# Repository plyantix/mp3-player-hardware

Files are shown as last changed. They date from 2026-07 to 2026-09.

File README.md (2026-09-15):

# MiniMusicBox

An open source, RP2350 based MP3 player, with LiPo battery charging, USB-C, MicroSD storage, high fidelity analog audio, and a black & white LCD screen.

Although this version of the project will work, I would not recommend building it, as it has a design flaw leading to high idle battery consumption. This will be fixed in a future revision.

This board was designed with the manufacturing tolerances of [JLCPCB](https://jlcpcb.com/) in mind.

(Incomplete) firmware [here](https://github.com/plyantix/mp3-project-software).

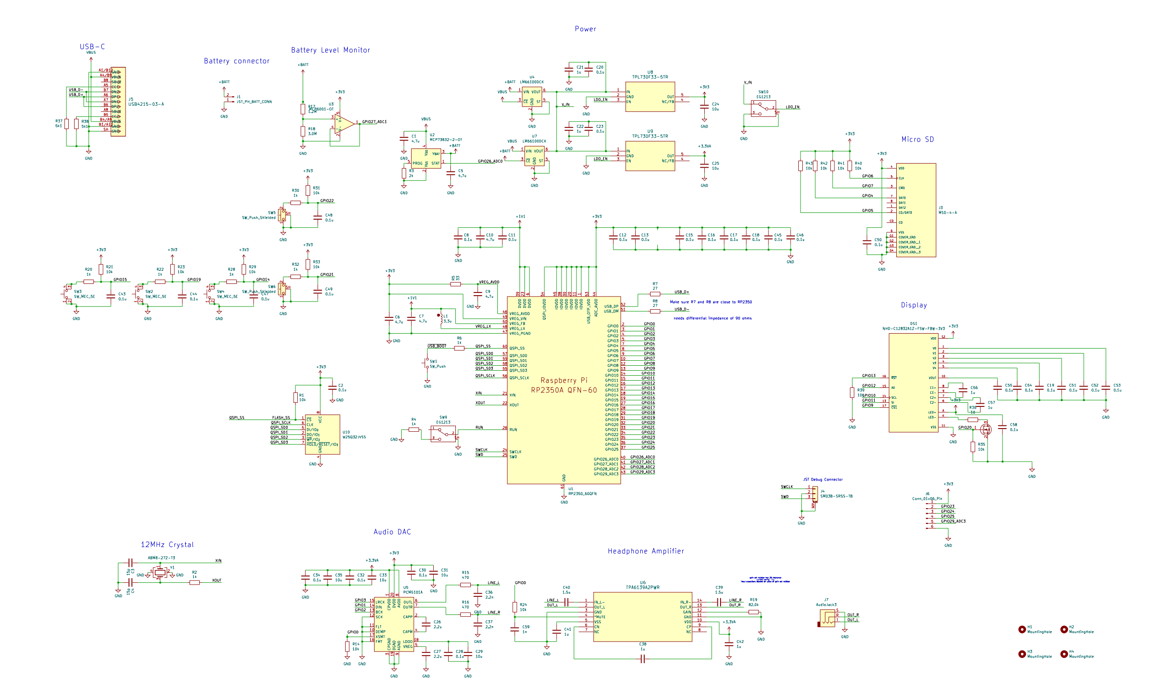
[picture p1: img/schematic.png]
PCB Schematic

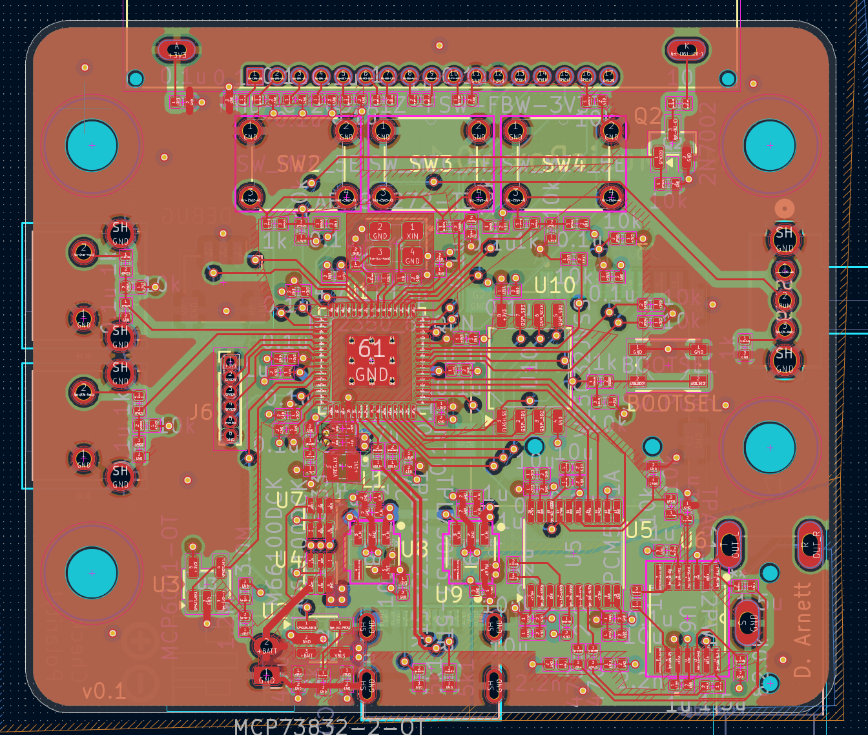
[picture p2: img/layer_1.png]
PCB layout layer 1

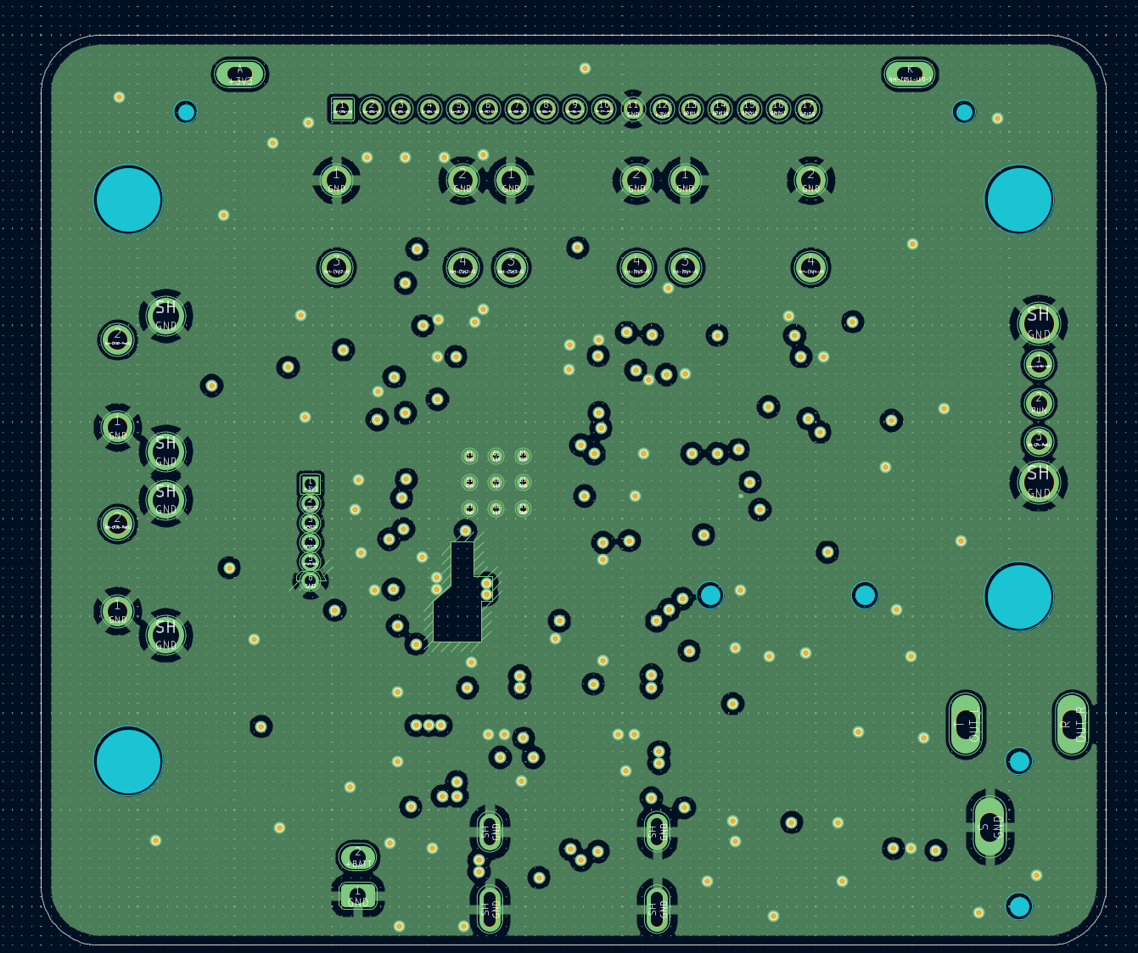
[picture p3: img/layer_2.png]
PCB layout layer 2

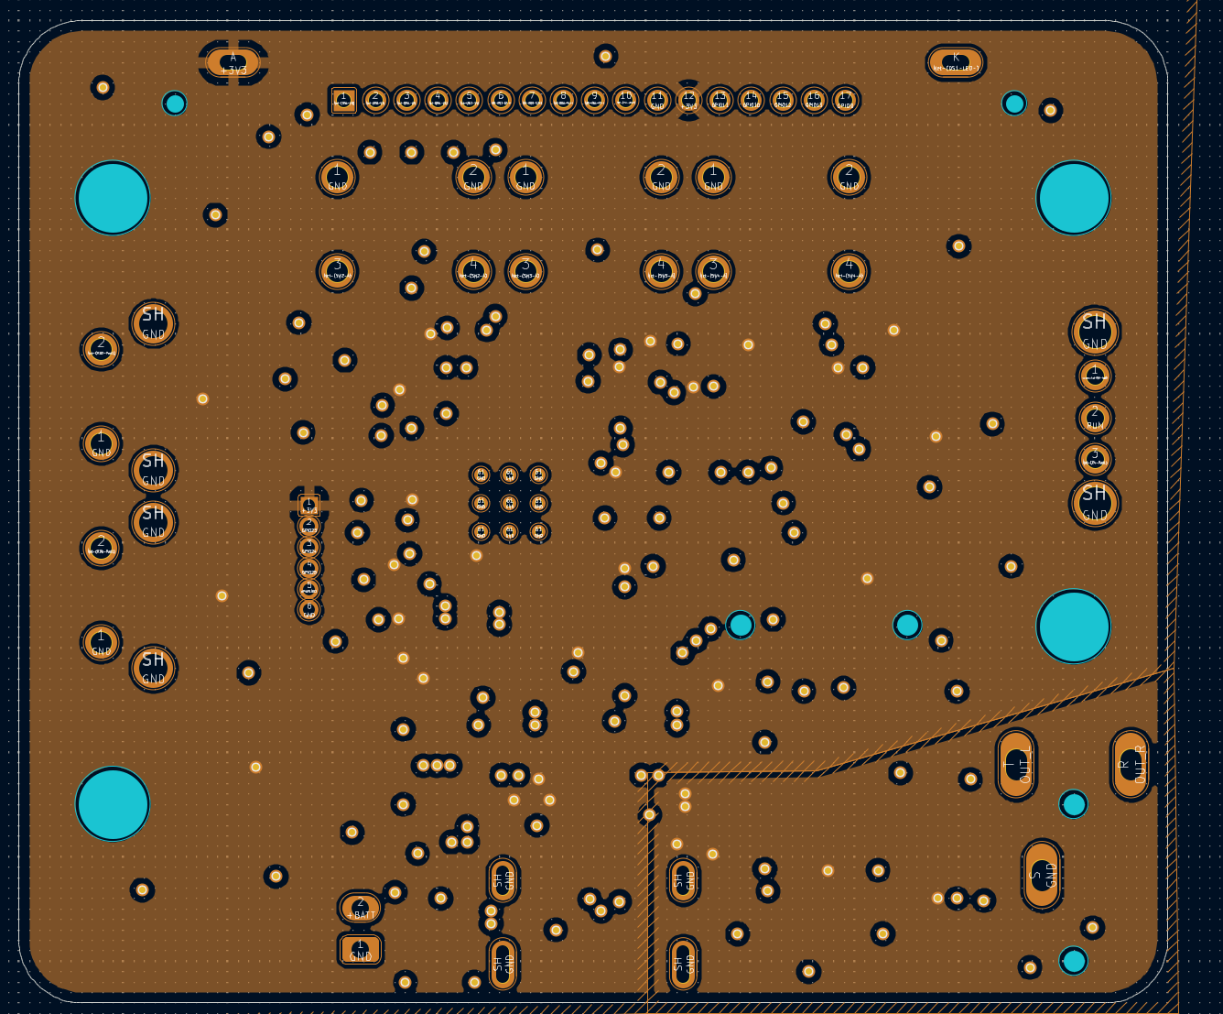
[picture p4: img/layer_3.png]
PCB layout layer 3

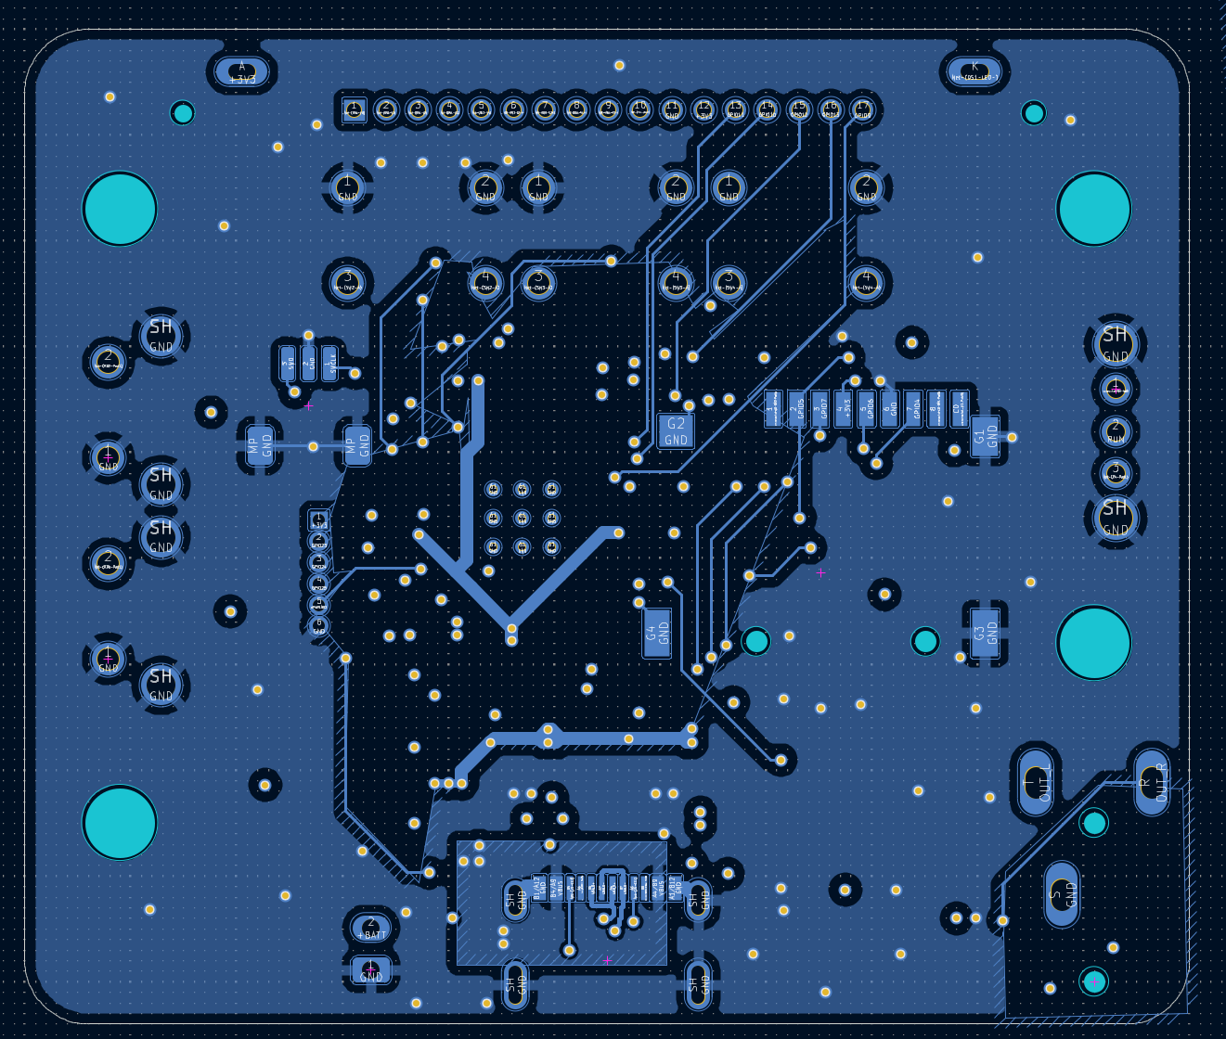
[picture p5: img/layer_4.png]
PCB layout layer 4

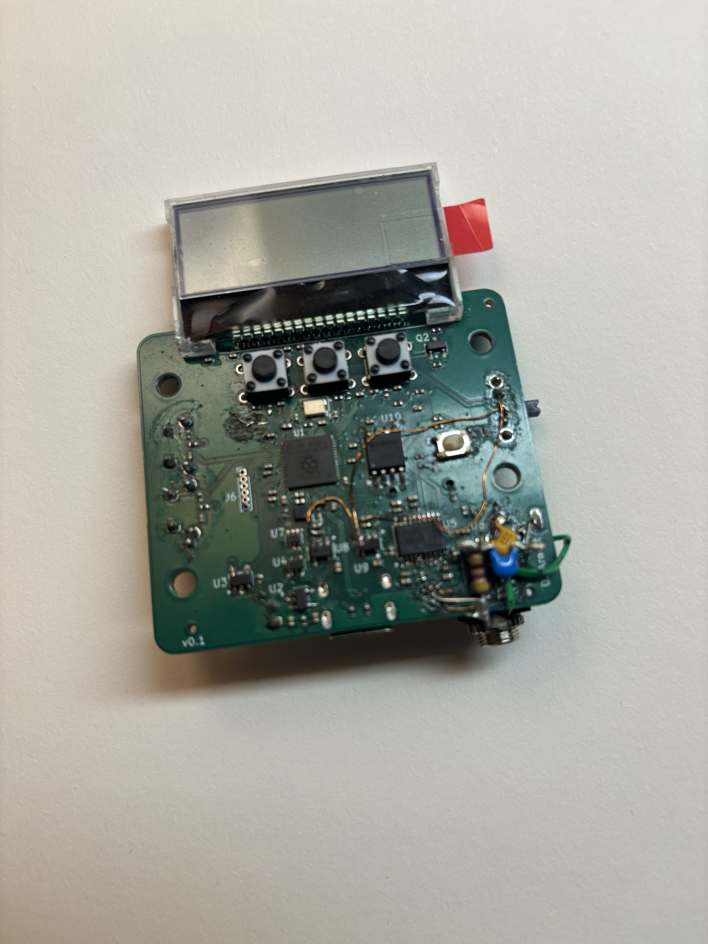
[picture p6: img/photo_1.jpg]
Photograph of fabricated and assembled PCB

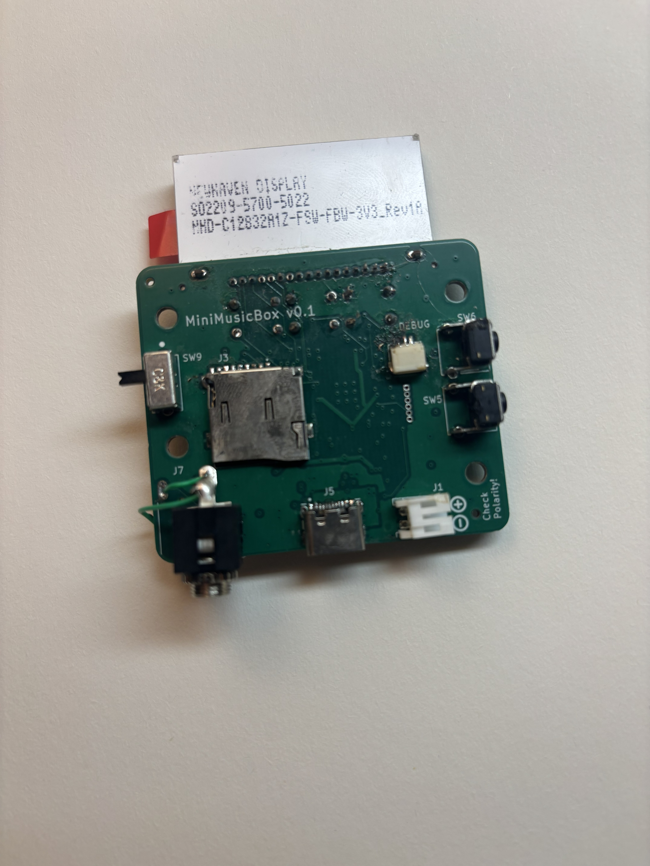
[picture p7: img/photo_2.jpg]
Backside of PCB


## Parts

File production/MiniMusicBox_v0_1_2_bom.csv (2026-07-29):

Designator | Footprint | Quantity | Value | LCSC Part #
BOOTSEL | SW_Push_1P1T_NO_Vertical_Wuerth_434133025816 | 1 | SW_Push
C1, C10, C5, C6, C7, C9 | 0402 | 6 | 4.7u
C11, C12, C13, C15, C16, C17, C18, C19, C2, C20, C23, C28, C30, C32, C34, C43, C44, C45, C46, C47, C48, C49, C50, C51, C52, C53, C54, C55, C58, C8 | 0402 | 30 | 0.1u
C21, C22, C38, C41, C42, C56, C57 | 0402 | 7 | 1u
C24, C25, C29, C31, C33, C35 | 0402 | 6 | 10u
C26, C27 | 0402 | 2 | 2.2u
C3, C4 | 0402 | 2 | 15p
C36, C37 | 0402 | 2 | 2.2n
C39, C40 | 0402 | 2 | 1.5u
C59 | 0402 | 1 | 1n
DEBUG | JST_SH_SM03B-SRSS-TB_1x03-1MP_P1.00mm_Horizontal | 1 | SM03B-SRSS-TB
DS1 | LCD_NHD-C12832A1Z-FSW-FBW-3V3 | 1 | NHD-C12832A1Z-FSW-FBW-3V3
J1 | JST_PH_S2B-PH-K_1x02_P2.00mm_Horizontal | 1 | JST_PH_BATT_CONN
J3 | CUI_MSD-4-A | 1 | MSD-4-A
J5 | CONN_8p94X6p5X3p16_12L_GCC | 1 | USB4215-03-A
J6 | PinHeader_1x06_P1.00mm_Vertical | 1 | Conn_01x06_Pin
J7 | KYCON_STX-3000 | 1 | AudioJack3
L1 | L_pol_2016 | 1 | 3.3u
Q2 | SOT-23 | 1 | 2N7002
R1, R14, R21, R23, R24, R29, R31, R33, R35, R39, R40, R41, R42, R43 | 0402 | 14 | 10k
R15, R16 | 0402 | 2 | 470
R17 | 0402 | 1 | 1.2M
R18 | 0402 | 1 | 3.0M
R19 | 0402 | 1 | 82.0k
R2, R20, R22, R28, R30, R32, R4, R6 | 0402 | 8 | 1k
R3 | 0402 | 1 | 2k
R36 | 0402 | 1 | 10
R37, R38 | 0402 | 2 | 5k1
R5 | 0402 | 1 | 33
R7, R8 | 0402 | 2 | 27
SW2, SW3, SW4 | SW4_1825910-B_TEC | 3 | SW_MEC_5E
SW5, SW6 | SW2_1825027-A_TEC | 2 | SW_Push_Shielded
SW9 | OS102011MA1QN1_CNK | 1 | EG1213
U1 | RP2350-QFN-60-1EP_7x7_P0.4mm_EP3.4x3.4mm_ThermalVias | 1 | RP2350_60QFN
U10 | SOIC-8_5.3x5.3mm_P1.27mm | 1 | W25Q32JVSS
U2 | SOT-23-5 | 1 | MCP73832-2-OT
U3 | SOT-23-5 | 1 | MCP6001-OT
U4, U7 | SOT-363_SC-70-6 | 2 | LM66100DCK
U5 | TSSOP-20_4.4x6.5mm_P0.65mm | 1 | PCM5101A
U6 | PW14 | 1 | TPA6139A2PWR
U8, U9 | SOT23-5-A_TPK | 2 | TPL730F33-5TR
Y1 | Crystal_SMD_3225-4Pin_3.2x2.5mm | 1 | ABM8-272-T3

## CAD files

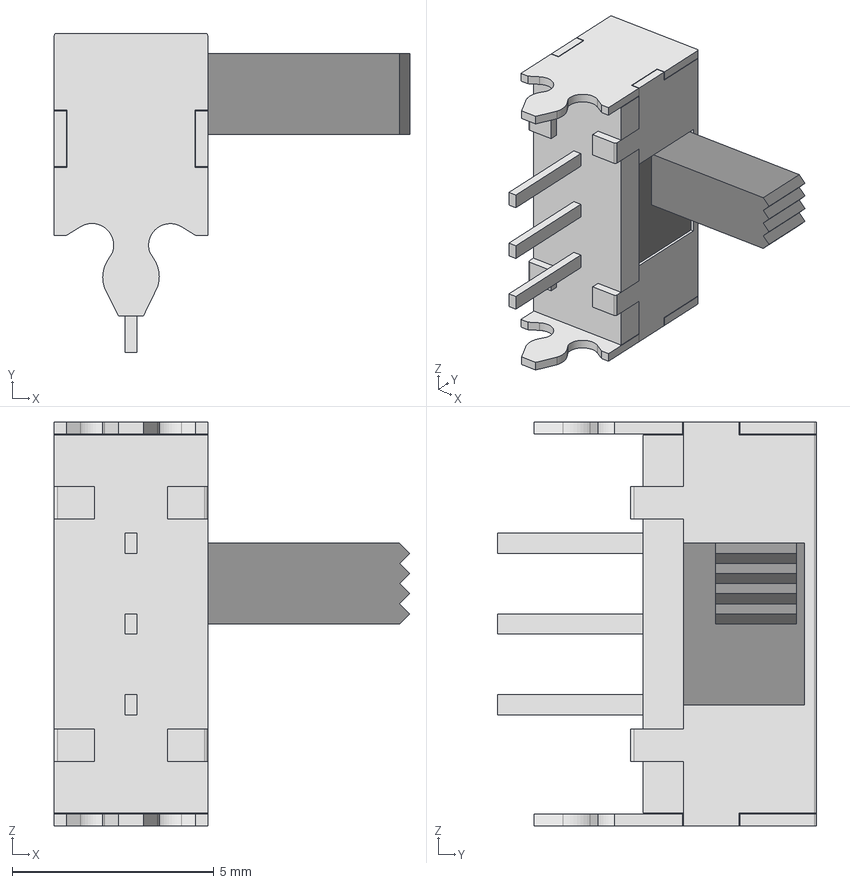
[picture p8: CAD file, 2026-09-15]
3dmodels/EG1213.step
8.80 x 7.90 x 10.00 mm

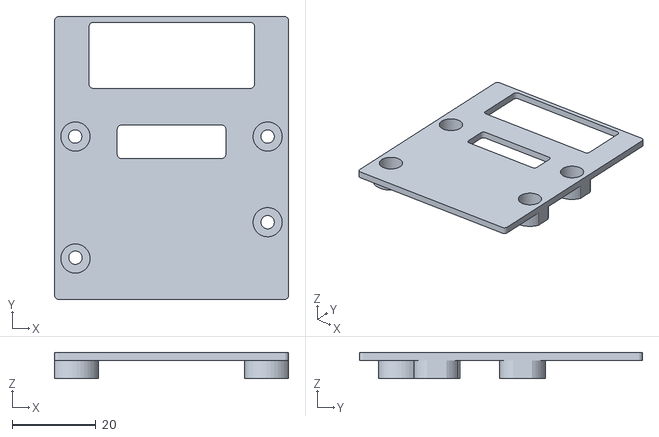
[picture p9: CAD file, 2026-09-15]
case_part2.STL
56.0 x 67.7 x 6.30

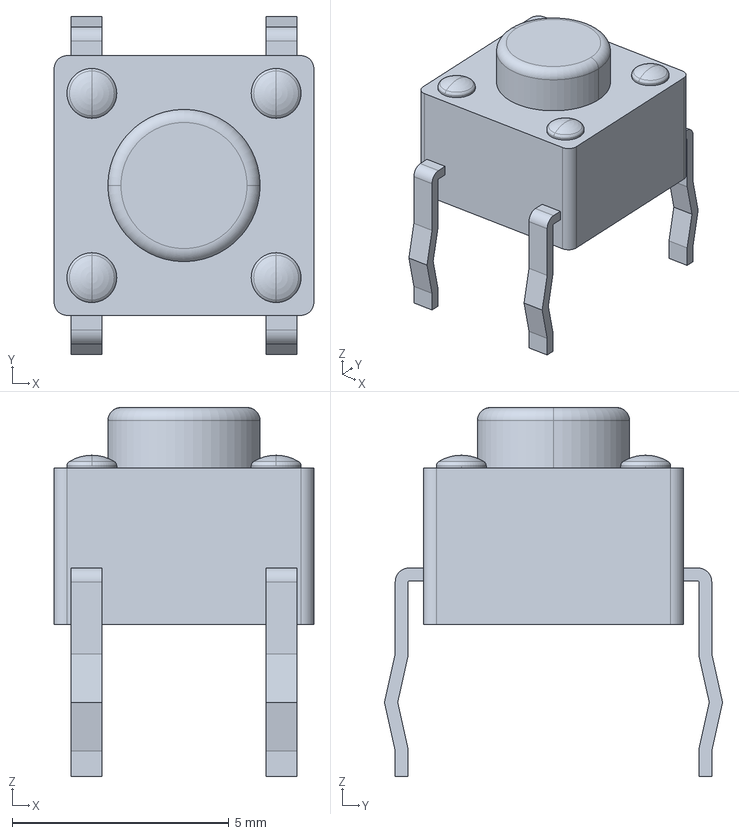
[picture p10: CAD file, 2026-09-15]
3dmodels/c-1825910-6-c-3d.stp
5.99 x 7.80 x 8.51 mm

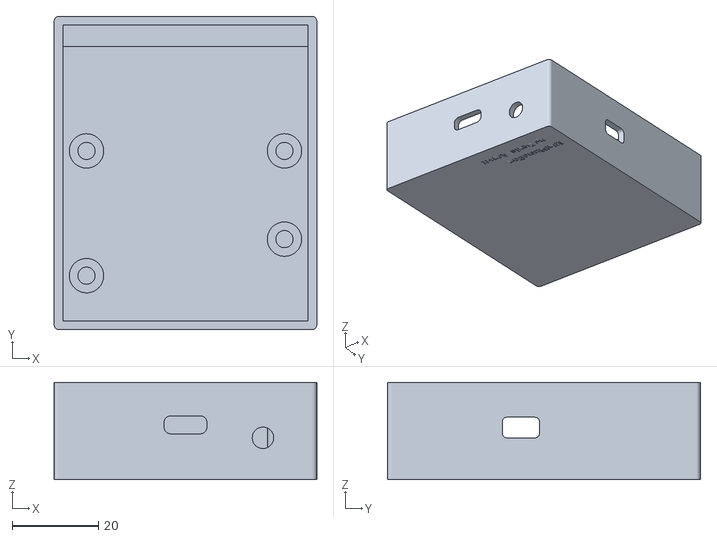
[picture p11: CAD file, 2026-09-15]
case_part1.STL
61.0 x 72.7 x 22.6

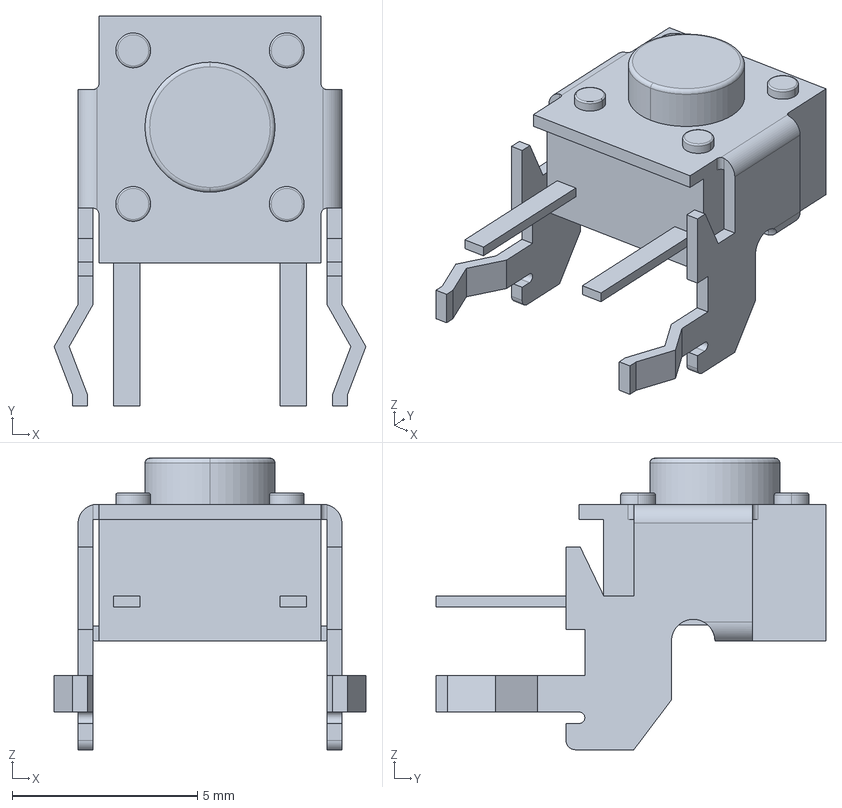
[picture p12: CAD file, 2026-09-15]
3dmodels/c-1825027-5-g-3d.stp
8.41 x 10.5 x 7.86 mm

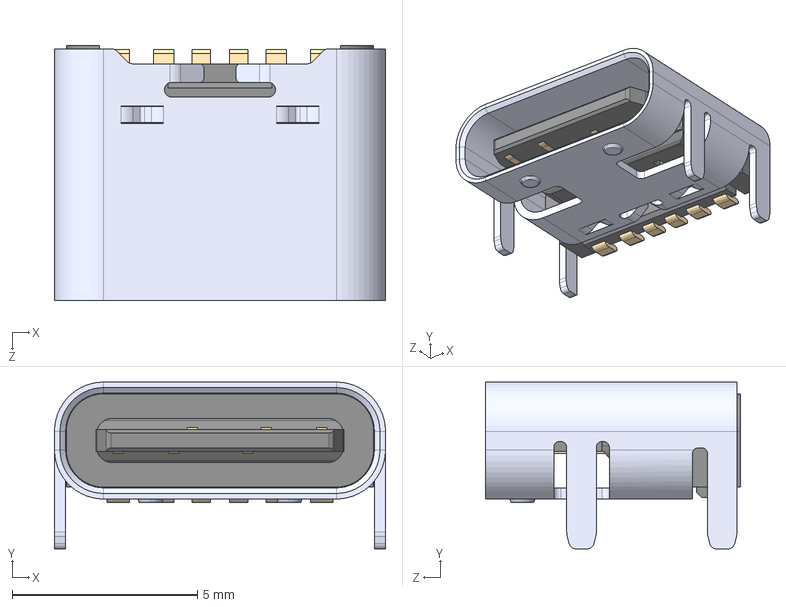
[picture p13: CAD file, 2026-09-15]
3dmodels/USB4125-GF-A_REVA2.step
8.94 x 4.51 x 6.90 mm

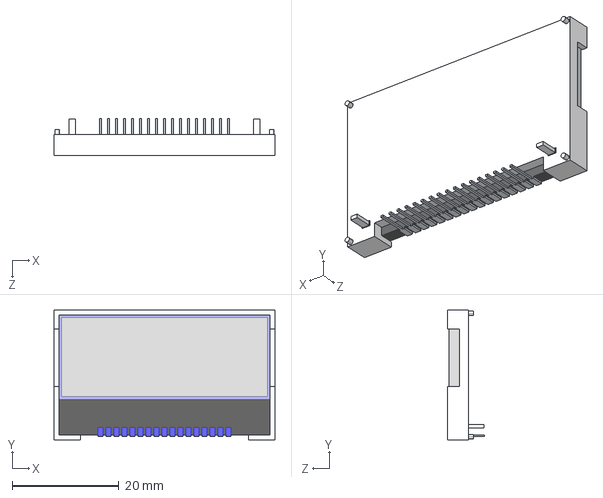
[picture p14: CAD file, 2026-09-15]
3dmodels/NHD-C12832A1Z.STEP
41.4 x 24.3 x 7.00 mm

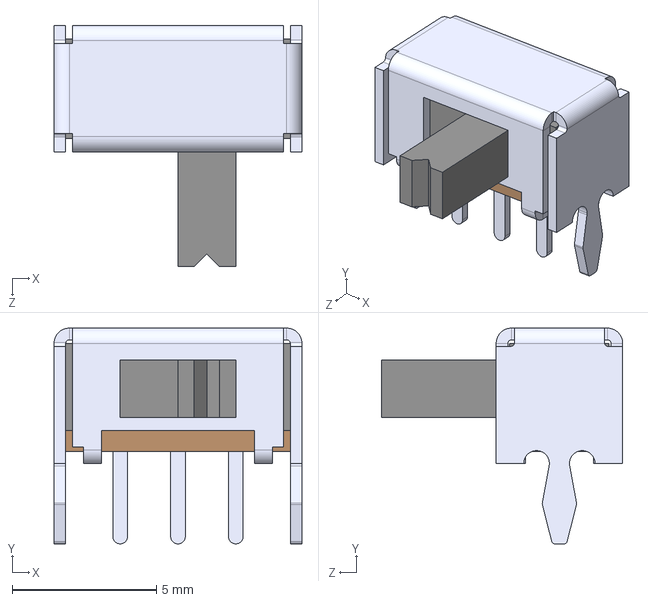
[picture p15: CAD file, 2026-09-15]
3dmodels/OS102011MA1QN1.STEP
8.61 x 7.49 x 8.38 mm

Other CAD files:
3dmodels/c-1825027-5-g-3d.stl
3dmodels/c-1825910-6-c-3d.stl

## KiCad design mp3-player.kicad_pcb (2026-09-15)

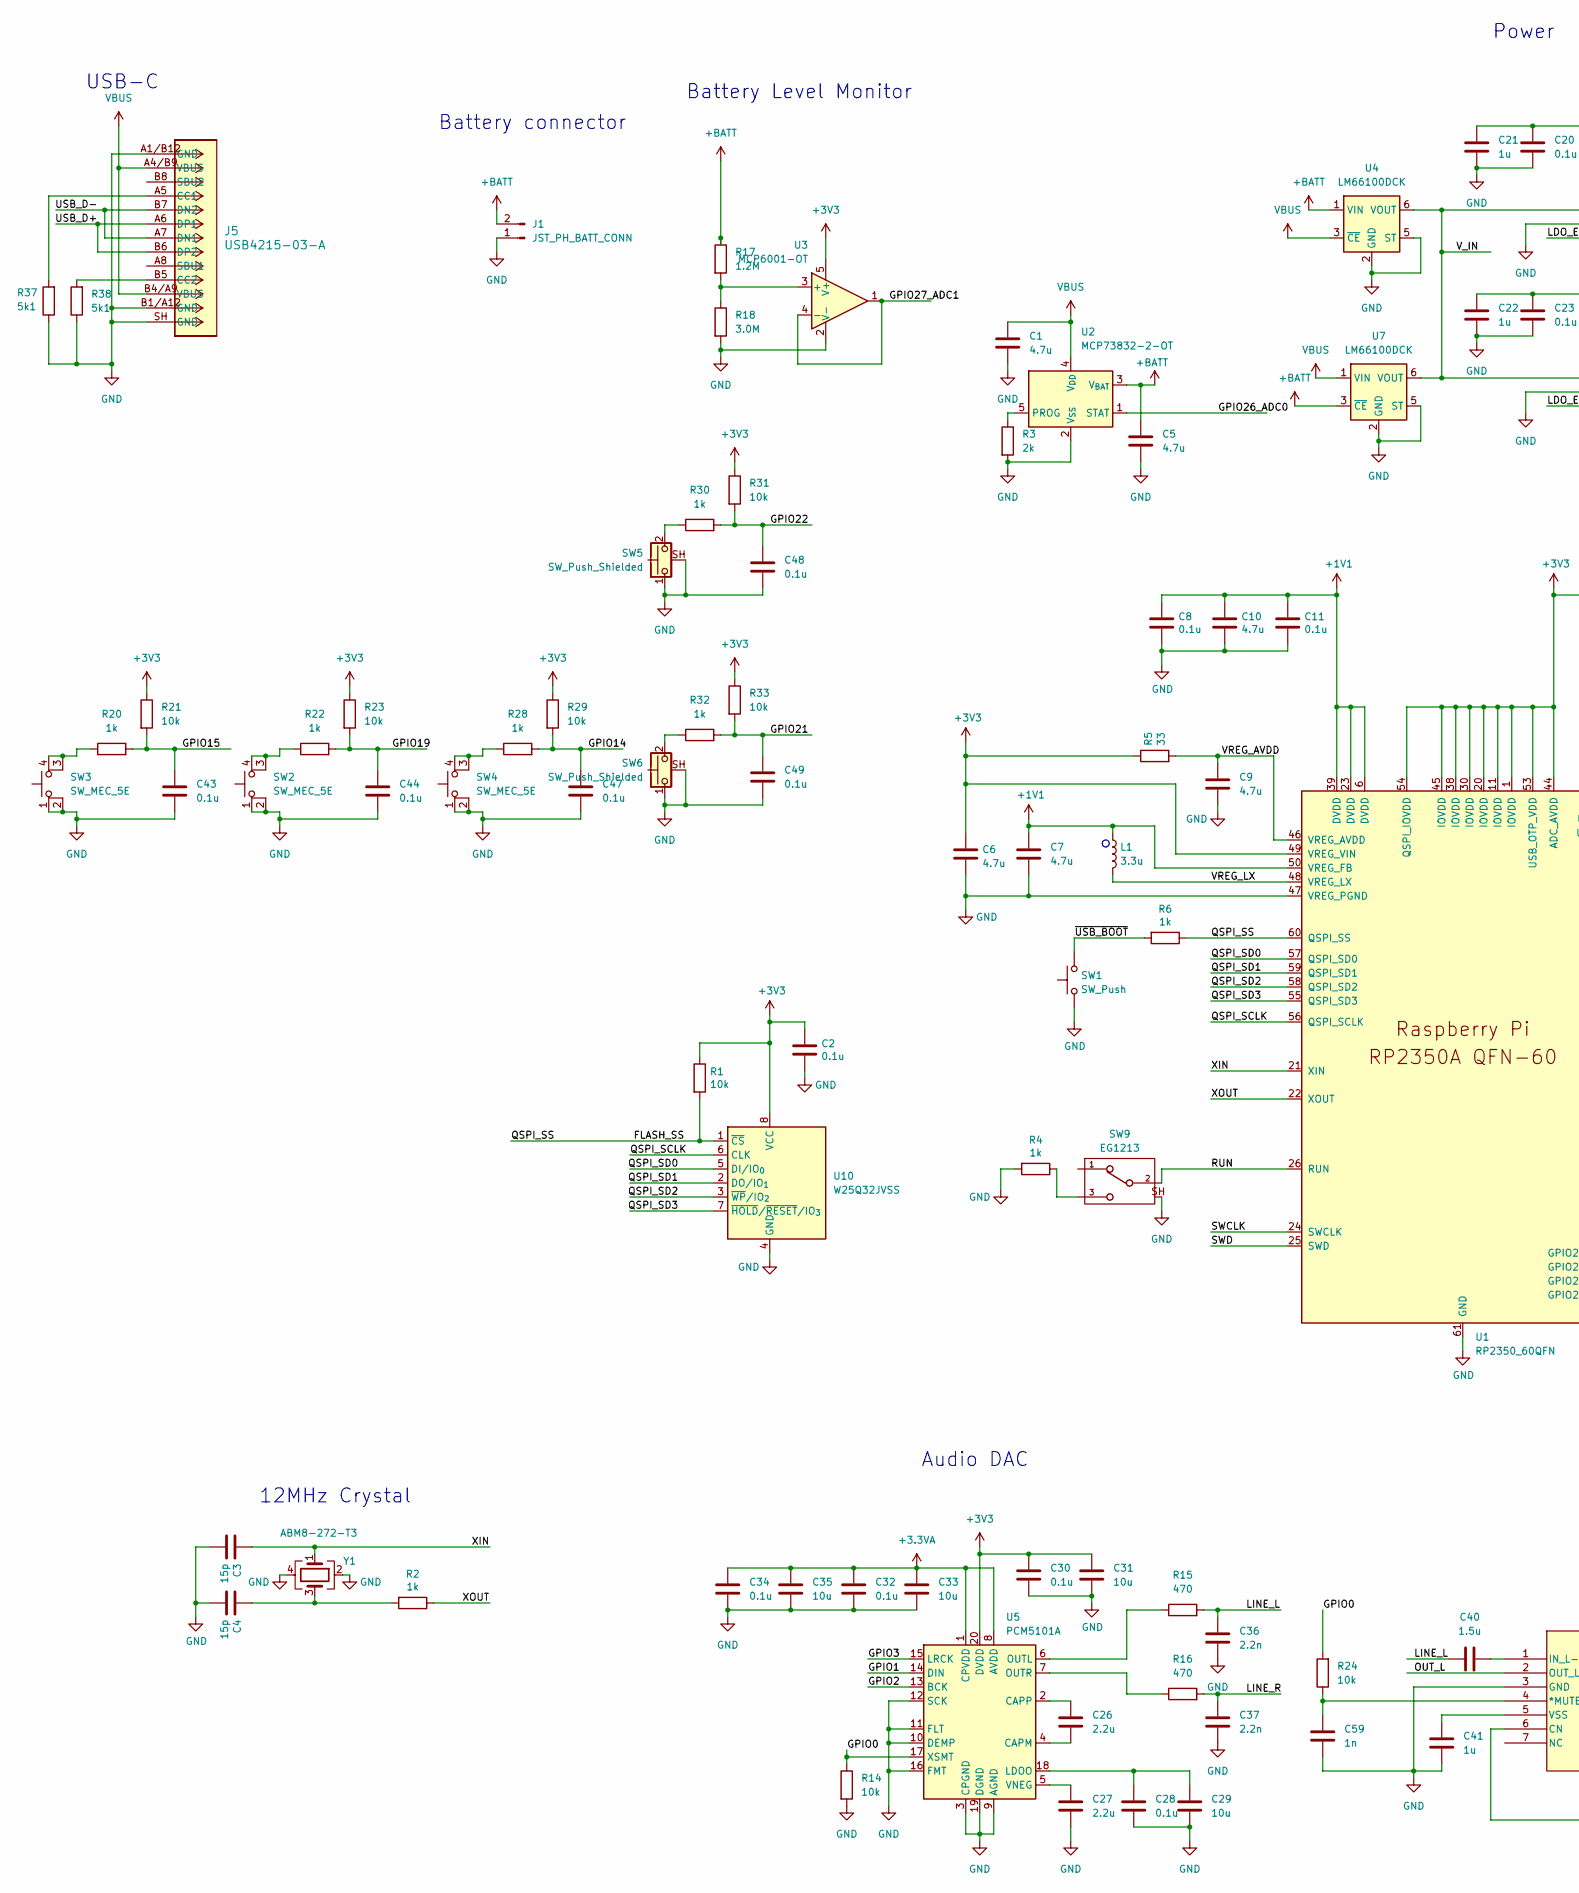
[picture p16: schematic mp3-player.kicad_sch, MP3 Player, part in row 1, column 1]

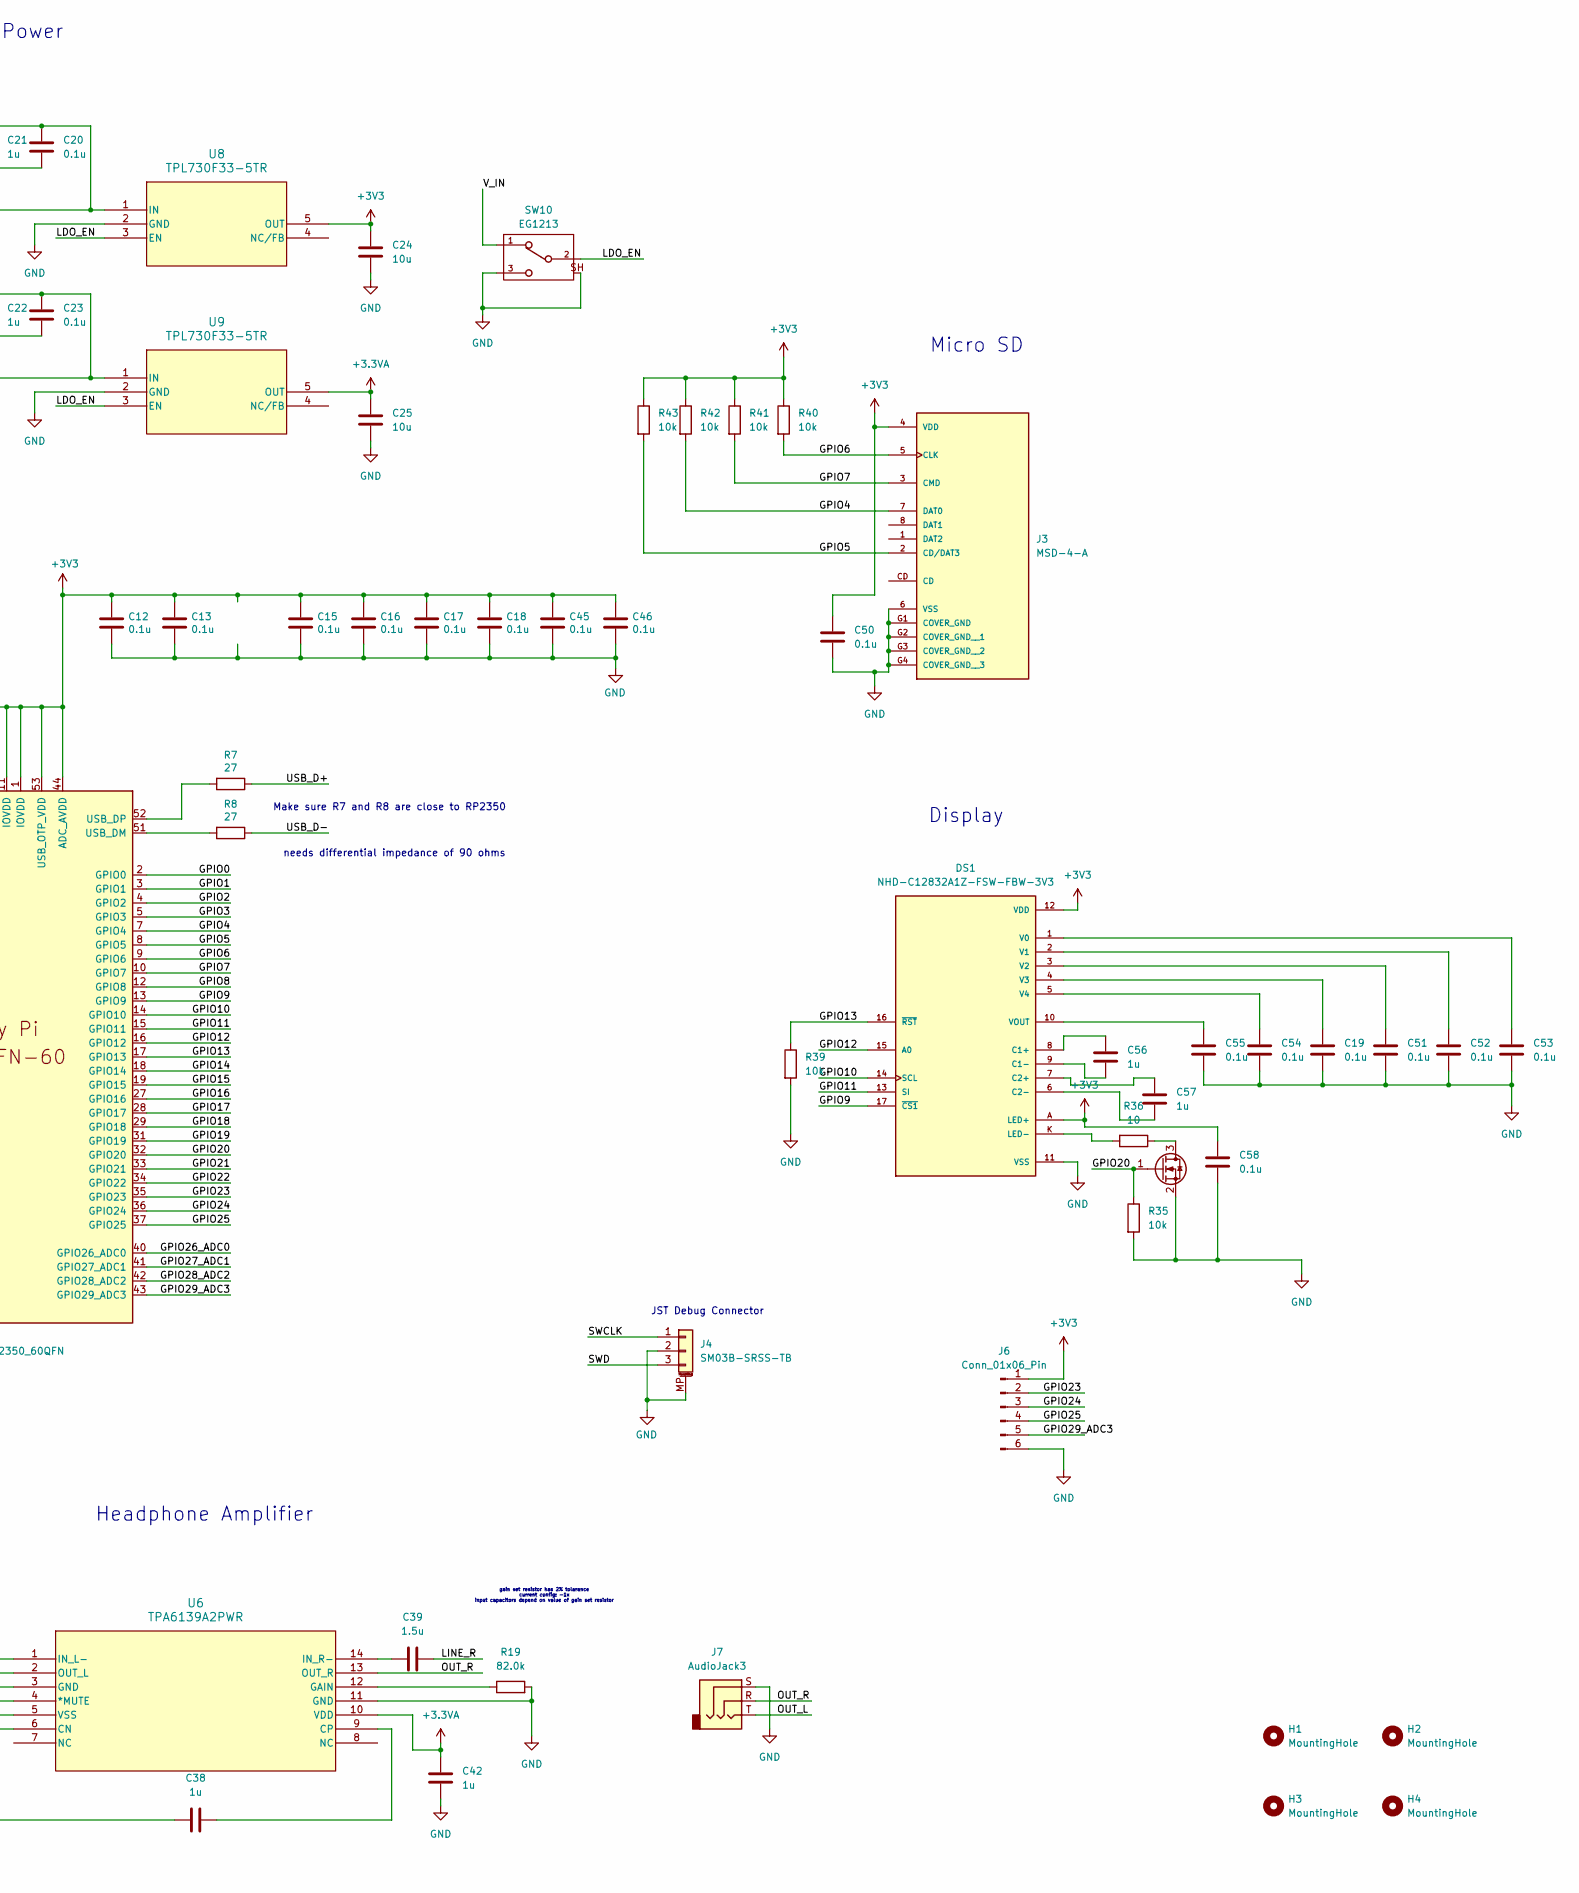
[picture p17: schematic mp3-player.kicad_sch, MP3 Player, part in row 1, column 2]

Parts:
C1, C5, C9, C10: 4.7u; C_0402_1005Metric_NoSilk
C2, C8, C11, C12, C13, C15, C16, C17, C18, C19, C20, C23, C28, C30, C32, C34, C43, C44, C45, C46, C47, C48, C49, C50, C51, C52, C53, C54, C55, C58: 0.1u; C_0402_1005Metric_NoSilk
C3, C4: 15p; C_0402_1005Metric_NoSilk
C6, C7: 4.7u; C_0402_1005Metric_small_pads
C21, C22, C38, C41, C42, C56, C57: 1u; C_0402_1005Metric_NoSilk
C24, C25, C29, C31, C33, C35: 10u; C_0402_1005Metric_NoSilk
C26, C27: 2.2u; C_0402_1005Metric_NoSilk
C36, C37: 2.2n; C_0402_1005Metric_NoSilk
C39, C40: 1.5u; C_0402_1005Metric_NoSilk
C59: 1n; C_0402_1005Metric_NoSilk
DS1: NHD-C12832A1Z-FSW-FBW-3V3; LCD_NHD-C12832A1Z-FSW-FBW-3V3; PARTREV 7
H1, H2, H3, H4: MountingHole; MountingHole_3.2mm_M3
J1: JST_PH_BATT_CONN; JST_PH_S2B-PH-K_1x02_P2.00mm_Horizontal
J3: MSD-4-A; CUI_MSD-4-A; PARTREV 1.0
J4: SM03B-SRSS-TB; JST_SH_SM03B-SRSS-TB_1x03-1MP_P1.00mm_Horizontal
J5: USB4215-03-A; CONN_8p94X6p5X3p16_12L_GCC
J6: Conn_01x06_Pin; PinHeader_1x06_P1.00mm_Vertical
J7: AudioJack3; KYCON_STX-3000
L1: 3.3u; L_pol_2016
Q2: 2N7002; SOT-23
R1, R14, R21, R23, R24, R29, R31, R33, R35, R39, R40, R41, R42, R43: 10k; R_0402_1005Metric_NoSilk
R2, R4, R6, R20, R22, R28, R30, R32: 1k; R_0402_1005Metric_NoSilk
R3: 2k; R_0402_1005Metric_NoSilk
R5: 33; R_0402_1005Metric_NoSilk
R7, R8: 27; R_0402_1005Metric_NoSilk
R15, R16: 470; R_0402_1005Metric_NoSilk
R17: 1.2M; R_0402_1005Metric_NoSilk
R18: 3.0M; R_0402_1005Metric_NoSilk
R19: 82.0k; R_0402_1005Metric_NoSilk
R36: 10; R_0402_1005Metric_NoSilk
R37, R38: 5k1; R_0402_1005Metric_NoSilk
SW1: SW_Push; SW_Push_1P1T_NO_Vertical_Wuerth_434133025816
SW2, SW3, SW4: SW_MEC_5E; SW4_1825910-B_TEC
SW5, SW6: SW_Push_Shielded; SW2_1825027-A_TEC
SW9, SW10: EG1213; OS102011MA1QN1_CNK
U1: RP2350_60QFN; RP2350-QFN-60-1EP_7x7_P0.4mm_EP3.4x3.4mm_ThermalVias
U2: MCP73832-2-OT; SOT-23-5
U3: MCP6001-OT; SOT-23-5
U4, U7: LM66100DCK; SOT-363_SC-70-6
U5: PCM5101A; TSSOP-20_4.4x6.5mm_P0.65mm
U6: TPA6139A2PWR; PW14
U8, U9: TPL730F33-5TR; SOT23-5-A_TPK
U10: W25Q32JVSS; SOIC-8_5.3x5.3mm_P1.27mm
Y1: ABM8-272-T3; Crystal_SMD_3225-4Pin_3.2x2.5mm

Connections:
+1V1: C7.1, C8.1, C10.1, C11.1, L1.1, U1.6 (DVDD), U1.23 (DVDD), U1.39 (DVDD), U1.50 (VREG_FB)
+3.3VA: C25.1, C32.1, C33.1, C34.1, C35.1, C42.1, U5.1 (CPVDD), U5.8 (AVDD), U6.10 (VDD), U9.5 (OUT)
+3V3: C2.1, C6.1, C12.1, C13.1, C15.1, C16.1, C17.1, C18.1, C24.1, C30.1, C31.1, C45.1, C46.1, C50.1, C58.1, DS1.12 (VDD), DS1.A (LED+), J3.4 (VDD), J6.1, R1.1, R5.1, R21.1, R23.1, R29.1, R31.1, R33.1, R40.1, R41.1, R42.1, R43.1, U1.1 (IOVDD), U1.11 (IOVDD), U1.20 (IOVDD), U1.30 (IOVDD), U1.38 (IOVDD), U1.44 (ADC_AVDD), U1.45 (IOVDD), U1.49 (VREG_VIN), U1.53 (USB_OTP_VDD), U1.54 (QSPI_IOVDD), U3.5 (V+), U5.20 (DVDD), U8.5 (OUT), U10.8 (VCC)
+BATT: C5.1, J1.2, R17.1, U2.3 (V_{BAT}), U4.1 (VIN), U7.3 (~CE)
/FLASH_SS: R1.2, R6.1, U1.60 (QSPI_SS), U10.1 (~CS)
/GPIO0: R14.1, R24.2, U1.2 (GPIO0), U5.17 (XSMT)
/GPIO1: U1.3 (GPIO1), U5.14 (DIN)
/GPIO2: U1.4 (GPIO2), U5.13 (BCK)
/GPIO3: U1.5 (GPIO3), U5.15 (LRCK)
/GPIO4: J3.7 (DAT0), R42.2, U1.7 (GPIO4)
/GPIO5: J3.2 (CD/DAT3), R43.2, U1.8 (GPIO5)
/GPIO6: J3.5 (CLK), R40.2, U1.9 (GPIO6)
/GPIO7: J3.3 (CMD), R41.2, U1.10 (GPIO7)
/GPIO8: U1.12 (GPIO8)
/GPIO9: DS1.17 (~CS1), U1.13 (GPIO9)
/GPIO10: DS1.14 (SCL), U1.14 (GPIO10)
/GPIO11: DS1.13 (SI), U1.15 (GPIO11)
/GPIO12: DS1.15 (A0), U1.16 (GPIO12)
/GPIO13: DS1.16 (~RST), R39.1, U1.17 (GPIO13)
/GPIO14: C47.1, R28.2, R29.2, U1.18 (GPIO14)
/GPIO15: C43.1, R20.2, R21.2, U1.19 (GPIO15)
/GPIO16: U1.27 (GPIO16)
/GPIO17: U1.28 (GPIO17)
/GPIO18: U1.29 (GPIO18)
/GPIO19: C44.1, R22.2, R23.2, U1.31 (GPIO19)
/GPIO20: Q2.1 (G), R35.1, U1.32 (GPIO20)
/GPIO21: C49.1, R32.2, R33.2, U1.33 (GPIO21)
/GPIO22: C48.1, R30.2, R31.2, U1.34 (GPIO22)
/GPIO23: J6.2, U1.35 (GPIO23)
/GPIO24: J6.3, U1.36 (GPIO24)
/GPIO25: J6.4, U1.37 (GPIO25)
/GPIO26_ADC0: U1.40 (GPIO26_ADC0), U2.1 (STAT)
/GPIO27_ADC1: U1.41 (GPIO27_ADC1), U3.1, U3.4 (-)
/GPIO28_ADC2: U1.42 (GPIO28_ADC2)
/GPIO29_ADC3: J6.5, U1.43 (GPIO29_ADC3)
/LINE_L: C36.1, C40.1, R15.2
/LINE_R: C37.1, C39.2, R16.2
/OUT_L: J7.T, U6.2 (OUT_L)
/OUT_R: J7.R, U6.13 (OUT_R)
/QSPI_SCLK: U1.56 (QSPI_SCLK), U10.6 (CLK)
/QSPI_SD0: U1.57 (QSPI_SD0), U10.5 (DI/IO_{0})
/QSPI_SD1: U1.59 (QSPI_SD1), U10.2 (DO/IO_{1})
/QSPI_SD2: U1.58 (QSPI_SD2), U10.3 (~WP/IO_{2})
/QSPI_SD3: U1.55 (QSPI_SD3), U10.7 (~HOLD/~RESET/IO_{3})
/RUN: SW9.2, U1.26 (RUN)
/SWCLK: J4.1, U1.24 (SWCLK); also elsewhere on the board
/SWD: J4.3, U1.25 (SWD); also elsewhere on the board
/USB_D+: J5.A6 (DP1), J5.B6 (DP2), R7.1
/USB_D-: J5.A7 (DN1), J5.B7 (DN2), R8.1
/VREG_AVDD: C9.1, R5.2, U1.46 (VREG_AVDD)
/VREG_LX: L1.2, U1.48 (VREG_LX)
/XIN: C3.1, U1.21 (XIN), Y1.1
/XOUT: R2.1, U1.22 (XOUT)
/~USB_BOOT: R6.2, SW1.2; also elsewhere on the board
GND: C1.2, C2.2, C3.2, C4.2, C5.2, C6.2, C7.2, C8.2, C9.2, C10.2, C11.2, C12.2, C13.2, C15.2, C16.2, C17.2, C18.2, C19.2, C20.2, C21.2, C22.2, C23.2, C24.2, C25.2, C27.2, C28.2, C29.2, C30.2, C31.2, C32.2, C33.2, C34.2, C35.2, C36.2, C37.2, C41.1, C42.2, C43.2, C44.2, C45.2, C46.2, C47.2, C48.2, C49.2, C50.2, C51.2, C52.2, C53.2, C54.2, C55.2, C58.2, C59.1, DS1.11 (VSS), J1.1, J3.6 (VSS), J3.G1 (COVER_GND), J3.G2 (COVER_GND__1), J3.G3 (COVER_GND__2), J3.G4 (COVER_GND__3), J4.2, J4.MP (MountPin), J5.A1/B12 (GND), J5.B1/A12 (GND), J5.SH (GND), J6.6, J7.S, Q2.2 (S), R3.2, R4.2, R14.2, R18.2, R19.2, R35.2, R37.1, R38.1, R39.2, SW1.1, SW2.1, SW2.2, SW3.1, SW3.2, SW4.1, SW4.2, SW5.1, SW5.SH (B), SW6.1, SW6.SH (B), SW9.SH, SW10.3, SW10.SH, U1.47 (VREG_PGND), U1.61 (GND), U2.2 (V_{SS}), U3.2 (V-), U4.2 (GND), U4.5 (ST), U5.3 (CPGND), U5.9 (AGND), U5.10 (DEMP), U5.11 (FLT), U5.12 (SCK), U5.16 (FMT), U5.19 (DGND), U6.3 (GND), U6.11 (GND), U7.2 (GND), U7.5 (ST), U8.2 (GND), U9.2 (GND), U10.4 (GND), Y1.2, Y1.4; also elsewhere on the board
unnamed: C4.1, R2.2, Y1.3
unnamed: C56.2, DS1.8 (C1+)
unnamed: C56.1, DS1.9 (C1-)
unnamed: C57.2, DS1.7 (C2+)
unnamed: C57.1, DS1.6 (C2-)
unnamed: DS1.K (LED-), R36.2
unnamed: C53.1, DS1.1 (V0)
unnamed: C52.1, DS1.2 (V1)
unnamed: C51.1, DS1.3 (V2)
unnamed: C19.1, DS1.4 (V3)
unnamed: C54.1, DS1.5 (V4)
unnamed: C55.1, DS1.10 (VOUT)
unnamed: J5.A5 (CC1), R37.2
unnamed: J5.B5 (CC2), R38.2
unnamed: Q2.3 (D), R36.1
unnamed: R4.1, SW9.3
unnamed: R30.1, SW5.2
unnamed: R32.1, SW6.2
unnamed: R22.1, SW2.3 (K), SW2.4 (A)
unnamed: R20.1, SW3.3 (K), SW3.4 (A)
unnamed: R28.1, SW4.3 (K), SW4.4 (A)
unnamed: R8.2, U1.51 (USB_DM)
unnamed: R7.2, U1.52 (USB_DP)
unnamed: R3.1, U2.5 (PROG)
unnamed: R17.2, R18.1, U3.3 (+)
unnamed: C26.2, U5.4 (CAPM)
unnamed: C26.1, U5.2 (CAPP)
unnamed: C28.1, C29.1, U5.18 (LDOO)
unnamed: R15.1, U5.6 (OUTL)
unnamed: R16.1, U5.7 (OUTR)
unnamed: C27.1, U5.5 (VNEG)
unnamed: C59.2, R24.1, U6.4 (*MUTE)
unnamed: C38.2, U6.6 (CN)
unnamed: C38.1, U6.9 (CP)
unnamed: R19.1, U6.12 (GAIN)
unnamed: C40.2, U6.1 (IN_L-)
unnamed: C39.1, U6.14 (IN_R-)
unnamed: C41.2, U6.5 (VSS)
VBUS: C1.1, J5.A4/B9 (VBUS), J5.B4/A9 (VBUS), U2.4 (V_{DD}), U4.3 (~CE), U7.1 (VIN)

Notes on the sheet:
USB-C
Battery connector
Micro SD
Power
12MHz Crystal
needs differential impedance of 90 ohms
Battery Level Monitor
JST Debug Connector
Audio DAC
gain set resistor has 2% tolarance current config: -1x input capacitors depend on value of gain set resistor
Make sure R7 and R8 are close to RP2350
Display
Headphone Amplifier

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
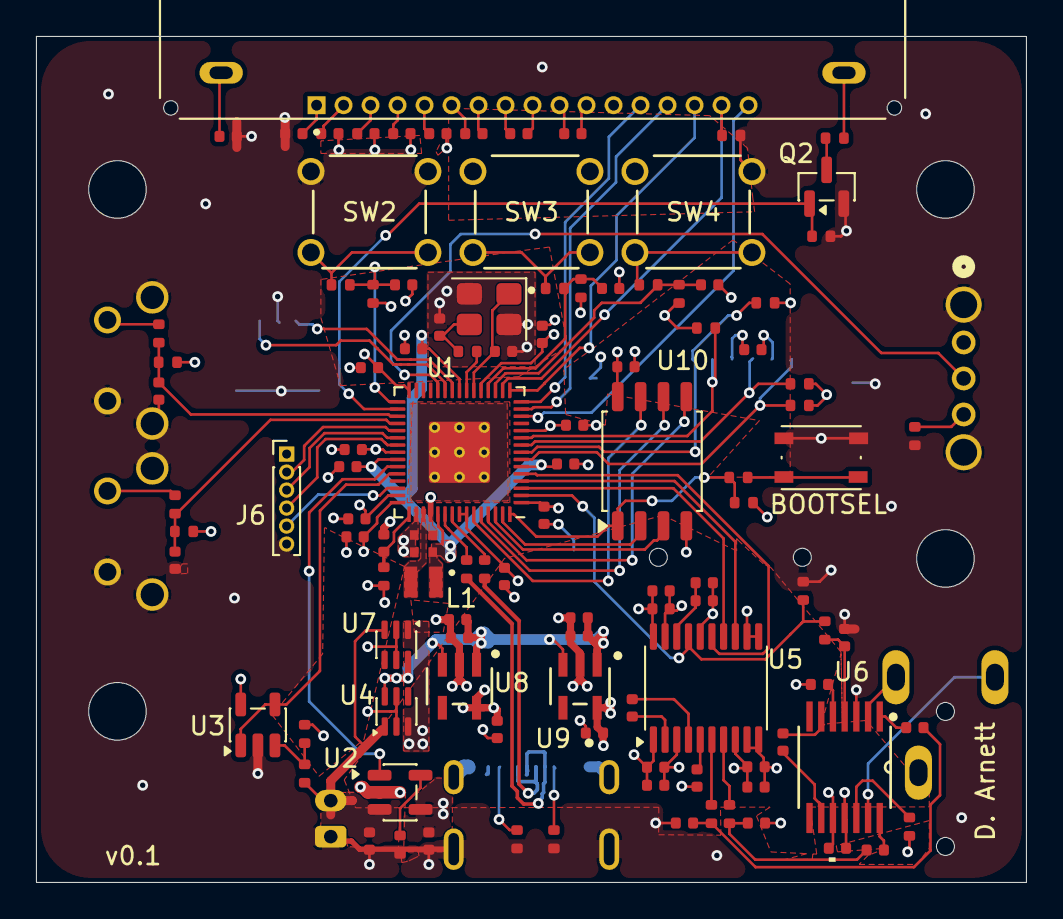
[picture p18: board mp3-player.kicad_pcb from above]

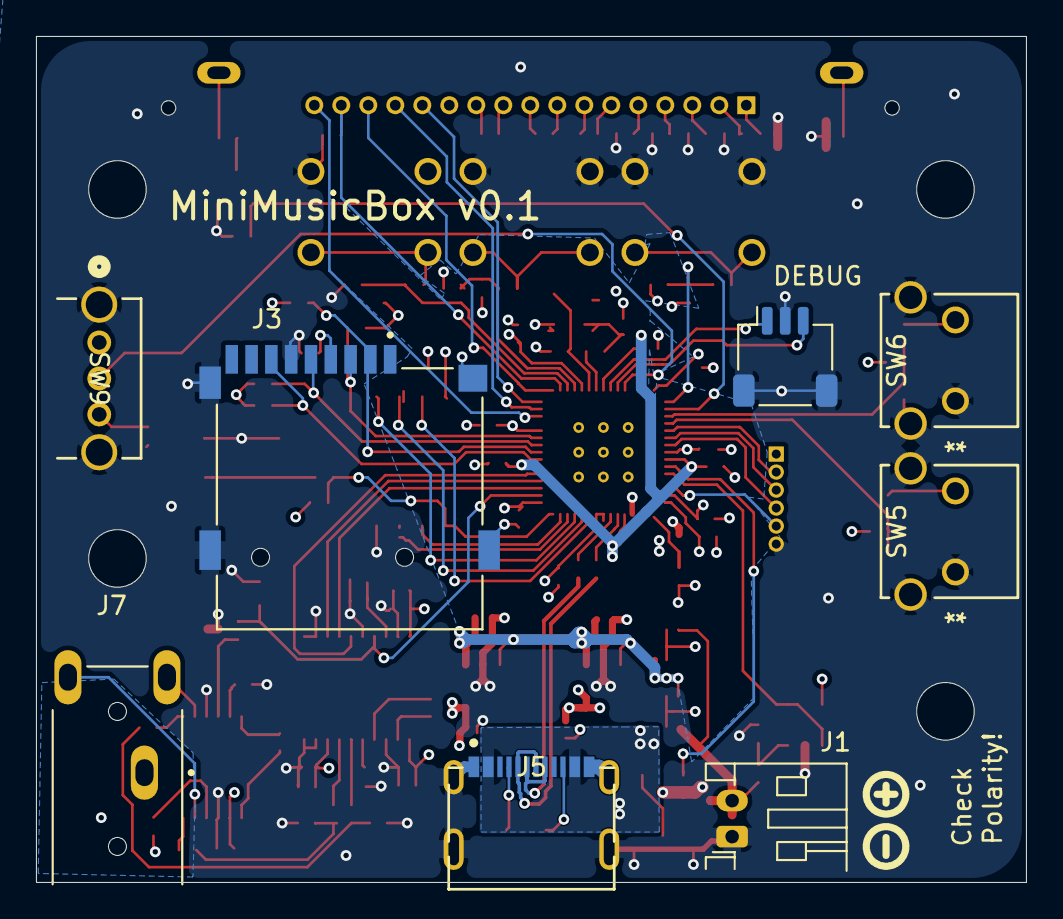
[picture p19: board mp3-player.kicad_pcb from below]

Board: 4 copper layers, 55.0 x 47.0 mm, 123 parts (8 on the bottom side), 90 nets.

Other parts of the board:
BOOTSEL: SW_Push; SW_Push_1P1T_NO_Vertical_Wuerth_434133025816
DEBUG: SM03B-SRSS-TB; JST_SH_SM03B-SRSS-TB_1x03-1MP_P1.00mm_Horizontal

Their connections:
/SWCLK: DEBUG.1; also elsewhere on the board
/SWD: DEBUG.3; also elsewhere on the board
/~USB_BOOT: BOOTSEL.2; also elsewhere on the board
GND: BOOTSEL.1, DEBUG.2, DEBUG.MP (MountPin); also elsewhere on the board

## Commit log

2026-07-29 production version 0.1
    [MiniMusicBox_v0_1_1_bom.csv, MiniMusicBox_v0_1_1_designators.csv, MiniMusicBox_v0_1_1_positions.csv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]
2026-09-15 cleaned project files, added readme
    [EG1213.step, NHD-C12832A1Z.STEP, OS102011MA1QN1.STEP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]
